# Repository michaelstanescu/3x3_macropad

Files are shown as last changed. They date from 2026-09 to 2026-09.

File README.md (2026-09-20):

# 3x3 Macropad (with Rotary Encoder)

A custom-designed, fully programmable mechanical macropad built to streamline desktop workflows and demonstrate full-cycle hardware development and embedded firmware integration. 

## System Features

*   **PCB Layout:** A compact 3x3 grid (9 keys) designed for macros, shortcuts, or a dedicated numpad.
*   **Rotary Encoder:** A clickable dial mapped for master volume control and audio muting.
*   **Microcontroller:** Arduino Pro Micro (ATmega32U4).
*   **Firmware:** QMK Firmware integration, allowing complete customization of every key switch and encoder action.
*   **Other Components:** Custom 3D-printed keycaps and rotary encoder knob.

## Hardware Design (KiCad)

The hardware architecture and PCB layout were developed using KiCad 10.0:

*   **Schematics:** A 3x3 switch matrix configured with diodes to prevent key ghosting, alongside integrated pin mappings for the rotary encoder and microcontroller.
*   **PCB Layout:** A compact board layout with optimized trace routing.

## QMK Firmware

The `/firmware` directory contains the configuration files (`keymap.c`, `keyboard.json`, and `rules.mk`) required to compile and flash the system for custom keybindings.

## Repository Structure

*   `/` (Root): The primary KiCad design files (`macropadpcb.kicad_pro`, `macropadpcb.kicad_sch`, `macropadpcb.kicad_pcb`).
*   `/firmware`: The QMK configuration source files.
*   `/docs`: System architecture documentation, including a PDF of the PCB layout, schematics, 3D renders, and physical images of the final build.

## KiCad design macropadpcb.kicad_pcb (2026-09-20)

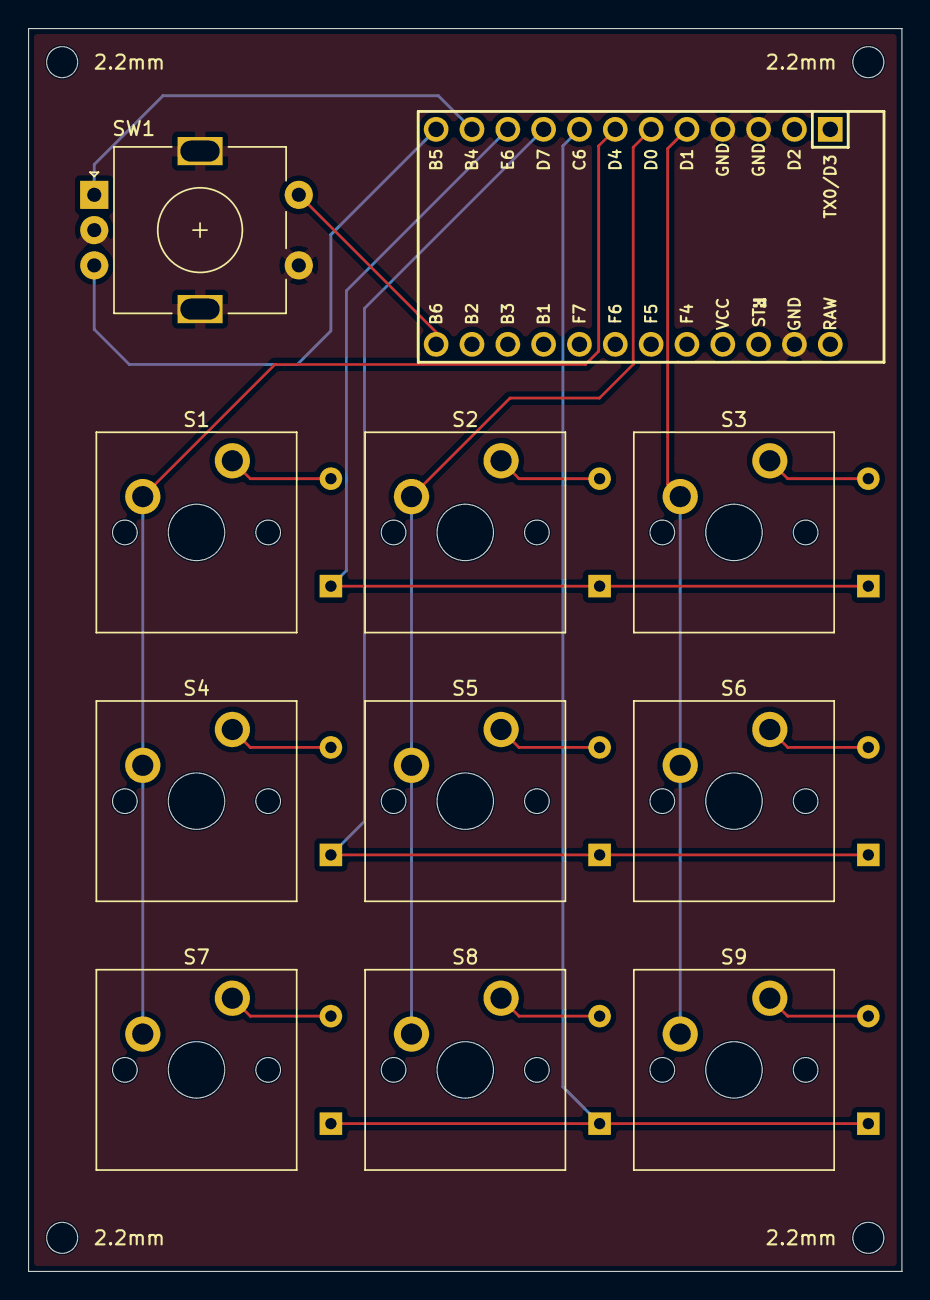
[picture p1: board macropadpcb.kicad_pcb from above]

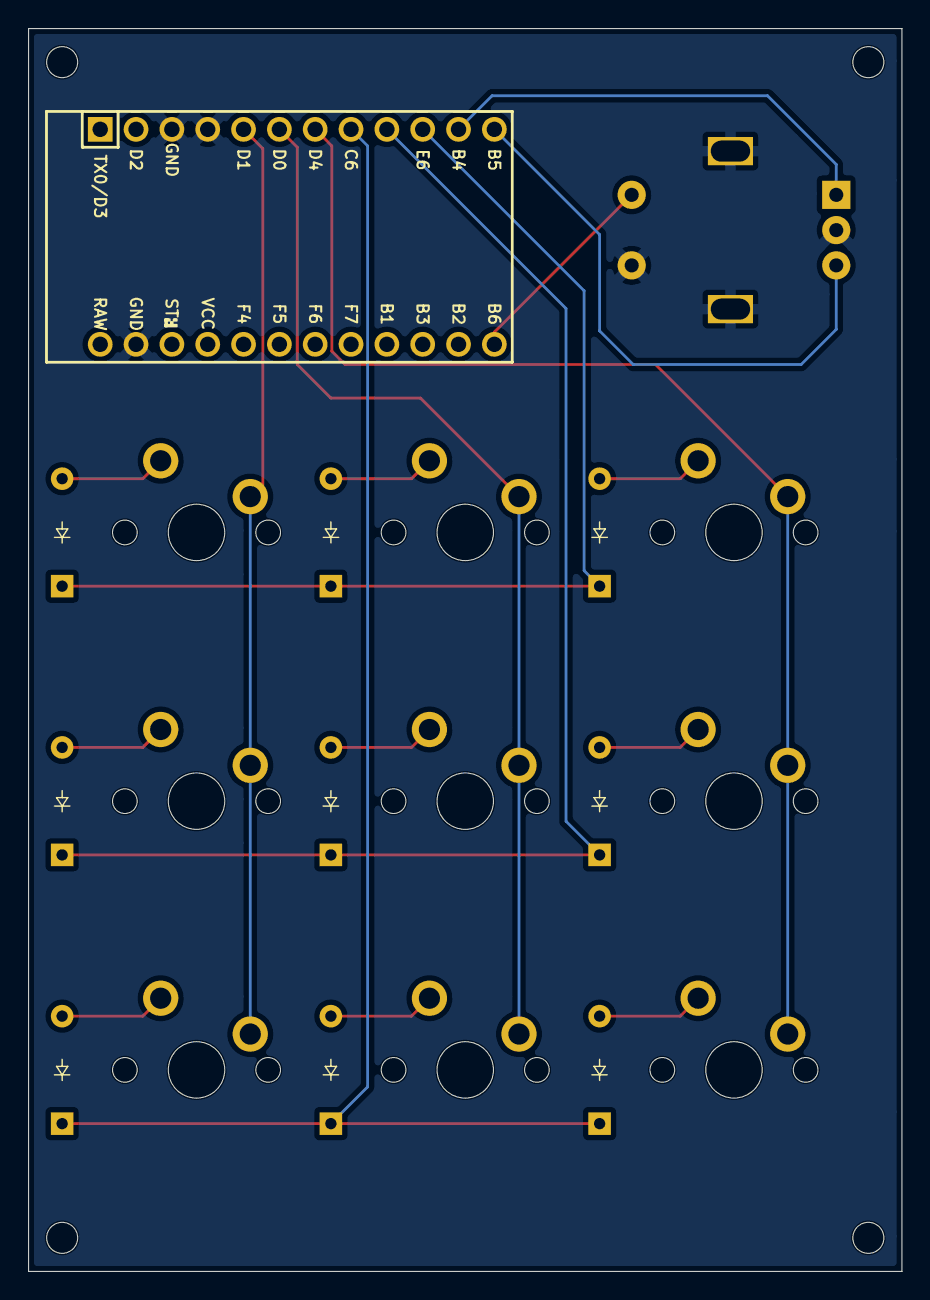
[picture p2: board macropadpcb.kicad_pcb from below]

Board: 2 copper layers, 61.9 x 88.1 mm, 24 parts (9 on the bottom side), 19 nets.

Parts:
2.2mm, 2.2mm#2, 2.2mm#3, 2.2mm#4: MountingHole_2.2mm_M2
D1, D2, D3, D4, D5, D6, D7, D8, D9: Diode_DO-35
S1, S2, S3, S4, S5, S6, S7, S8, S9: MX_PCB_1.00u
SW1: RotaryEncoder_Switch; RotaryEncoder_Alps_EC11E-Switch_Vertical_H20mm
U1: Arduino_Pro_Micro

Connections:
Column 0: S1.1, S4.1, S7.1, U1.7 (4/PD4)
Column 1: S2.1, S5.1, S8.1, U1.6 (3/PD0)
Column 2: S3.1, S6.1, S9.1, U1.5 (2/PD1)
ENC_A: SW1.A, U1.11 (8/PB4)
ENC_B: SW1.B, U1.12 (9/PB5)
ENC_SW: SW1.S2, U1.13 (10/PB6)
GND: SW1.C, SW1.MP, SW1.S1, U1.3 (GND), U1.4 (GND), U1.23 (GND)
unnamed: D1.2 (A), S1.2
unnamed: D2.2 (A), S2.2
unnamed: D3.2 (A), S3.2
unnamed: D4.2 (A), S4.2
unnamed: D5.2 (A), S5.2
unnamed: D6.2 (A), S6.2
unnamed: D7.2 (A), S7.2
unnamed: D8.2 (A), S8.2
unnamed: D9.2 (A), S9.2
Row 0: D1.1 (K), D2.1 (K), D3.1 (K), U1.10 (7/PE6)
Row 1: D4.1 (K), D5.1 (K), D6.1 (K), U1.9 (6/PD7)
Row 2: D7.1 (K), D8.1 (K), D9.1 (K), U1.8 (5/PC6)

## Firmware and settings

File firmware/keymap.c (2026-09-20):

#include QMK_KEYBOARD_H
#include "gpio.h" // Included so QMK knows how to read pins

// Define the layer index
#define _BASE 0

// Track the physical state of the encoder button
bool encoder_btn_pressed = false;

// The 3x3 Keymap Grid
const uint16_t PROGMEM keymaps[][MATRIX_ROWS][MATRIX_COLS] = {
    [_BASE] = LAYOUT(
        // Row 0: S1, S2, S3
        KC_MEDIA_PREV_TRACK, KC_MEDIA_PLAY_PAUSE, KC_MEDIA_NEXT_TRACK, 
        
        // Row 1: S4, S5, S6
        KC_F13,                KC_F14,                KC_F15,                
        
        // Row 2: S7, S8, S9
        KC_F16,                KC_F17,                KC_F18                 
    )
};

// 1. Initialize the Encoder Button Pin
void matrix_init_user(void) {
    // Set pin B6 as an input with an internal pull-up resistor
    gpio_set_pin_input_high(B6); 
}

// 2. Continuously read the Encoder Button Pin
void matrix_scan_user(void) {
    // Read the pin. It connects to Ground when pressed, so we invert it with "!"
    bool current_state = !gpio_read_pin(B6); 
    
    // If the state changed (you pressed or released it)
    if (current_state != encoder_btn_pressed) {
        encoder_btn_pressed = current_state;
        
        // Only trigger the mute toggle when the button is actively pressed down
        if (encoder_btn_pressed) {
            tap_code(KC_MUTE);   // Tap the Mute key once to toggle it on/off
        }
    }
}

// 3. Rotary Encoder Rotation
bool encoder_update_user(uint8_t index, bool clockwise) {
    if (index == 0) { 
        if (clockwise) {
            tap_code(KC_VOLD); // Right turn increases volume
        } else {
            tap_code(KC_VOLU); // Left turn decreases volume
        }
    }
    return false; 
}
